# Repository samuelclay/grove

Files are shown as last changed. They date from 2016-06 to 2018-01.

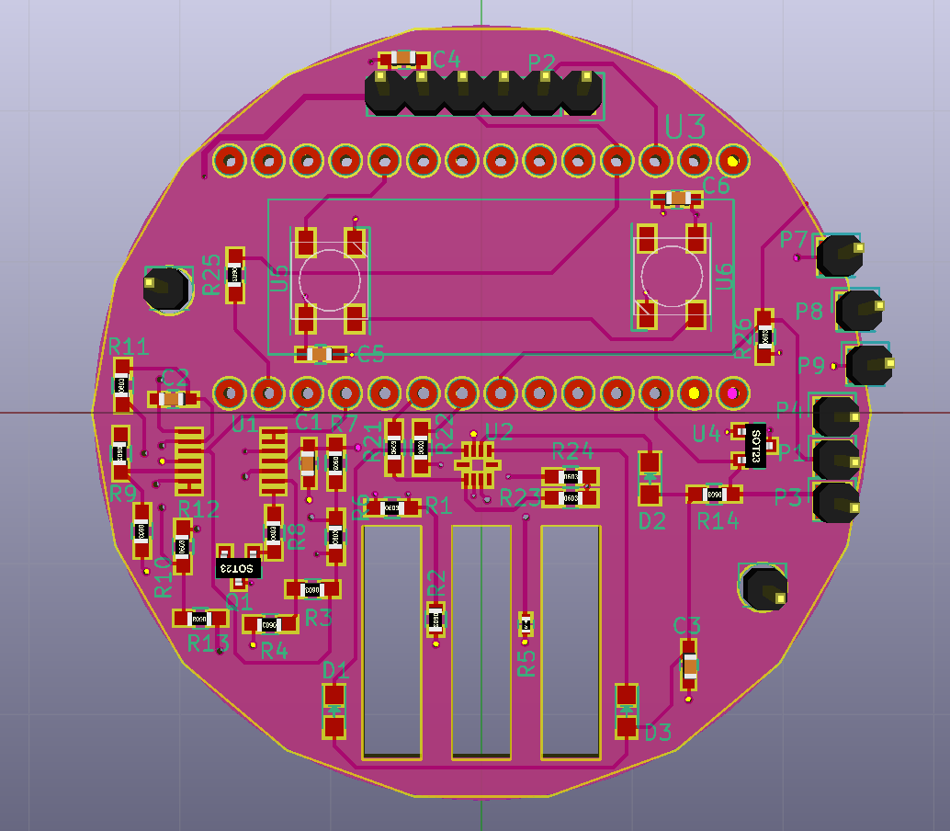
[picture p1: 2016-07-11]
sensor board/3D.PNG

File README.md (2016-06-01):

Grove
=====

Mailing list: grove-electronics@googlegroups.com

# Boards

1) Main board - Teensy shield
    - 4 x 3 pins for 144/m 5m strips on trunk
    - 4 x 5 pins (power + rgb) for dispatcher board
    - 3 pins (power + data) for breathing sensor
    - Power switch
    - PTC fuse + zener diode
    - 4 pins for buck converter, 12V -> 5V
    
2) Sensor board
    - 3 pins from mainboard (power, data)
    - Proximity sensor (SI1143x)
    - IR motion detector
    - "breathing" sensor
    - active LEDs

3) Dispatcher board
    - 4 x 5 pins input (power + rgb)
    - 4 PicoBucks (six pins in, six pins out)
    - 16 x 6 pin RGB LEDs (r±, g±, b±)

# Concerns

1) Power
    - 12V deep cycle marine batteries
    - Charging circuit
    - Solar array
    - Delivering 12V to each tree (voltage drop)
2) Firmware
    - Performance over time
    - Running 4x trunks vs 1 trunk 4 times
3) Lighting
    - Soldering high current LEDs
    - 144/m 5m vs splicing power

# Timeline

- May 31: Initial meeting
- June 8th: Dispatcher board rev #1 sent to printer
- June 9th: Main board rev #1 sent to printer
- June 10th: Sensor board rev #1 sent to printer
- July 1st: Boards return from printer, soldering begins
- July 6th: Final board revisions sent to printer
- July 27th: Final boards return from printer, soldering begins
- August 20th: Installation begins on playa
- August 28th: Burning Man begins

# Useful links:

Grove proposal: https://docs.google.com/presentation/d/1Oe51Et6uq_moFoTw9EoB07Vlh8WwSTc89PW6PQpZ1io/edit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
Grove budget: https://docs.google.com/spreadsheets/d/1ltcCgIae5ANJpvHL2A5ckWDxvADcpXeD_jZIF5hPCvg/edit#gid=0
Prototypes and earlier installation: https://cambridge.nuvustudio.com/studios/grove#tab-proposal-url

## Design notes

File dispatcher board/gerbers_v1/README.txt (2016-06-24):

Specifications
------------------
* 3mils tolerance on drills
* 7mils spacings everywhere (checked)

Files
------------------
grove-dispatcher-Edge.Cuts.gbr Edge Cuts

grove-dispatcher-B.Cu.gbr      copper layer (TOP)
grove-dispatcher-B.Mask.gbr    soldermask layer (TOP)
grove-dispatcher-B.SilkS.gbr   silkscreen layer (TOP)

grove-dispatcher-F.Cu.gbr      copper layer (TOP)
grove-dispatcher-F.Mask.gbr    soldermask layer (TOP)
grove-dispatcher-F.SilkS.gbr   silkscreen layer (TOP)

grove-dispatcher.drl           excellon drill data

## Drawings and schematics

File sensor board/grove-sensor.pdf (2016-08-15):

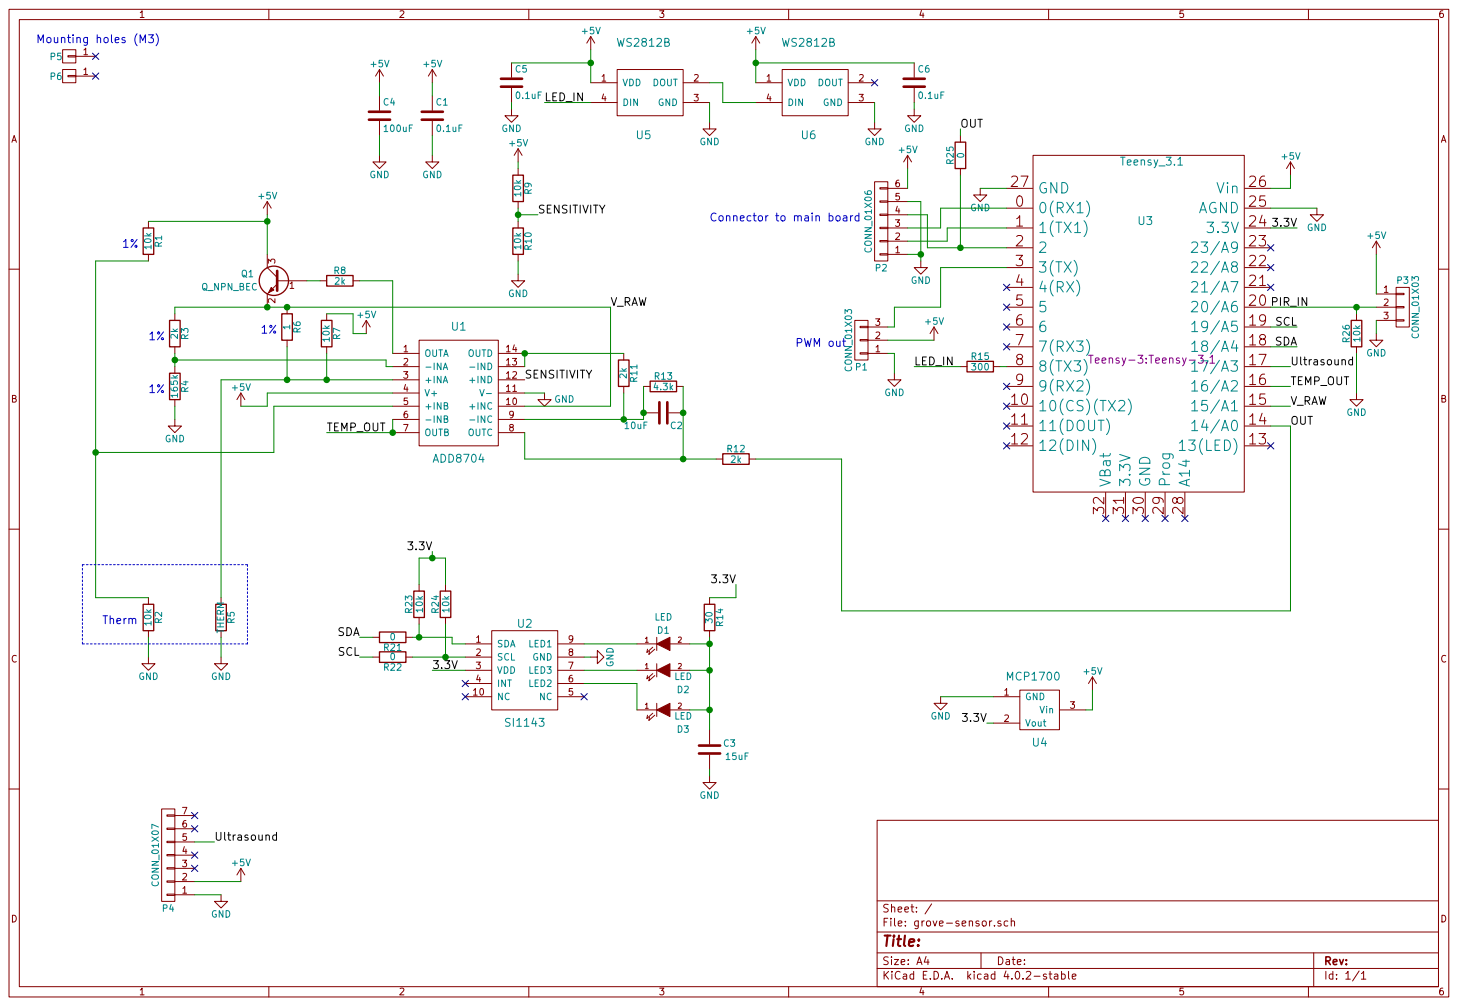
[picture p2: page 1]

+5V Connector to main board

File: grove-sensor.sch Sheet: /
Id: 1/1 Title:

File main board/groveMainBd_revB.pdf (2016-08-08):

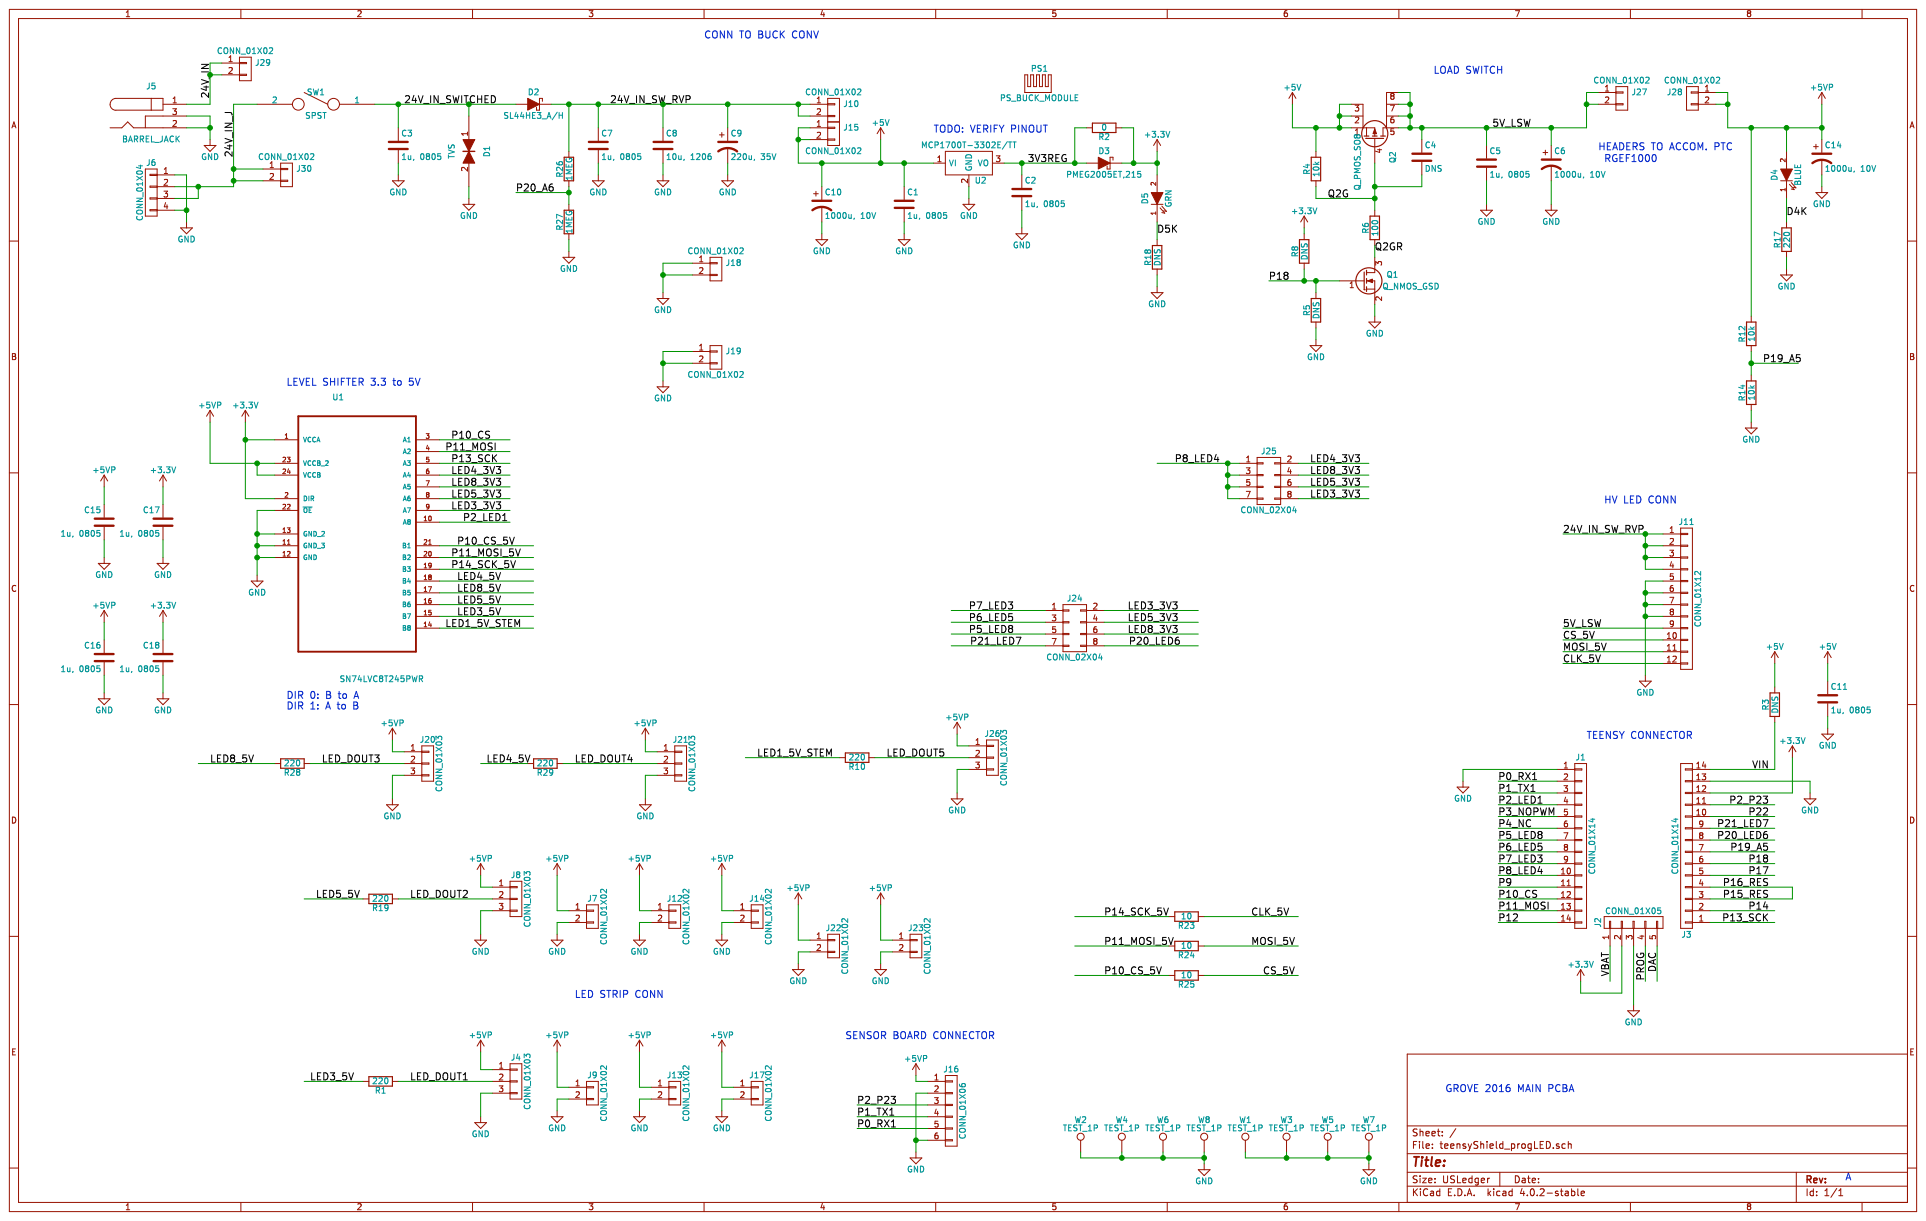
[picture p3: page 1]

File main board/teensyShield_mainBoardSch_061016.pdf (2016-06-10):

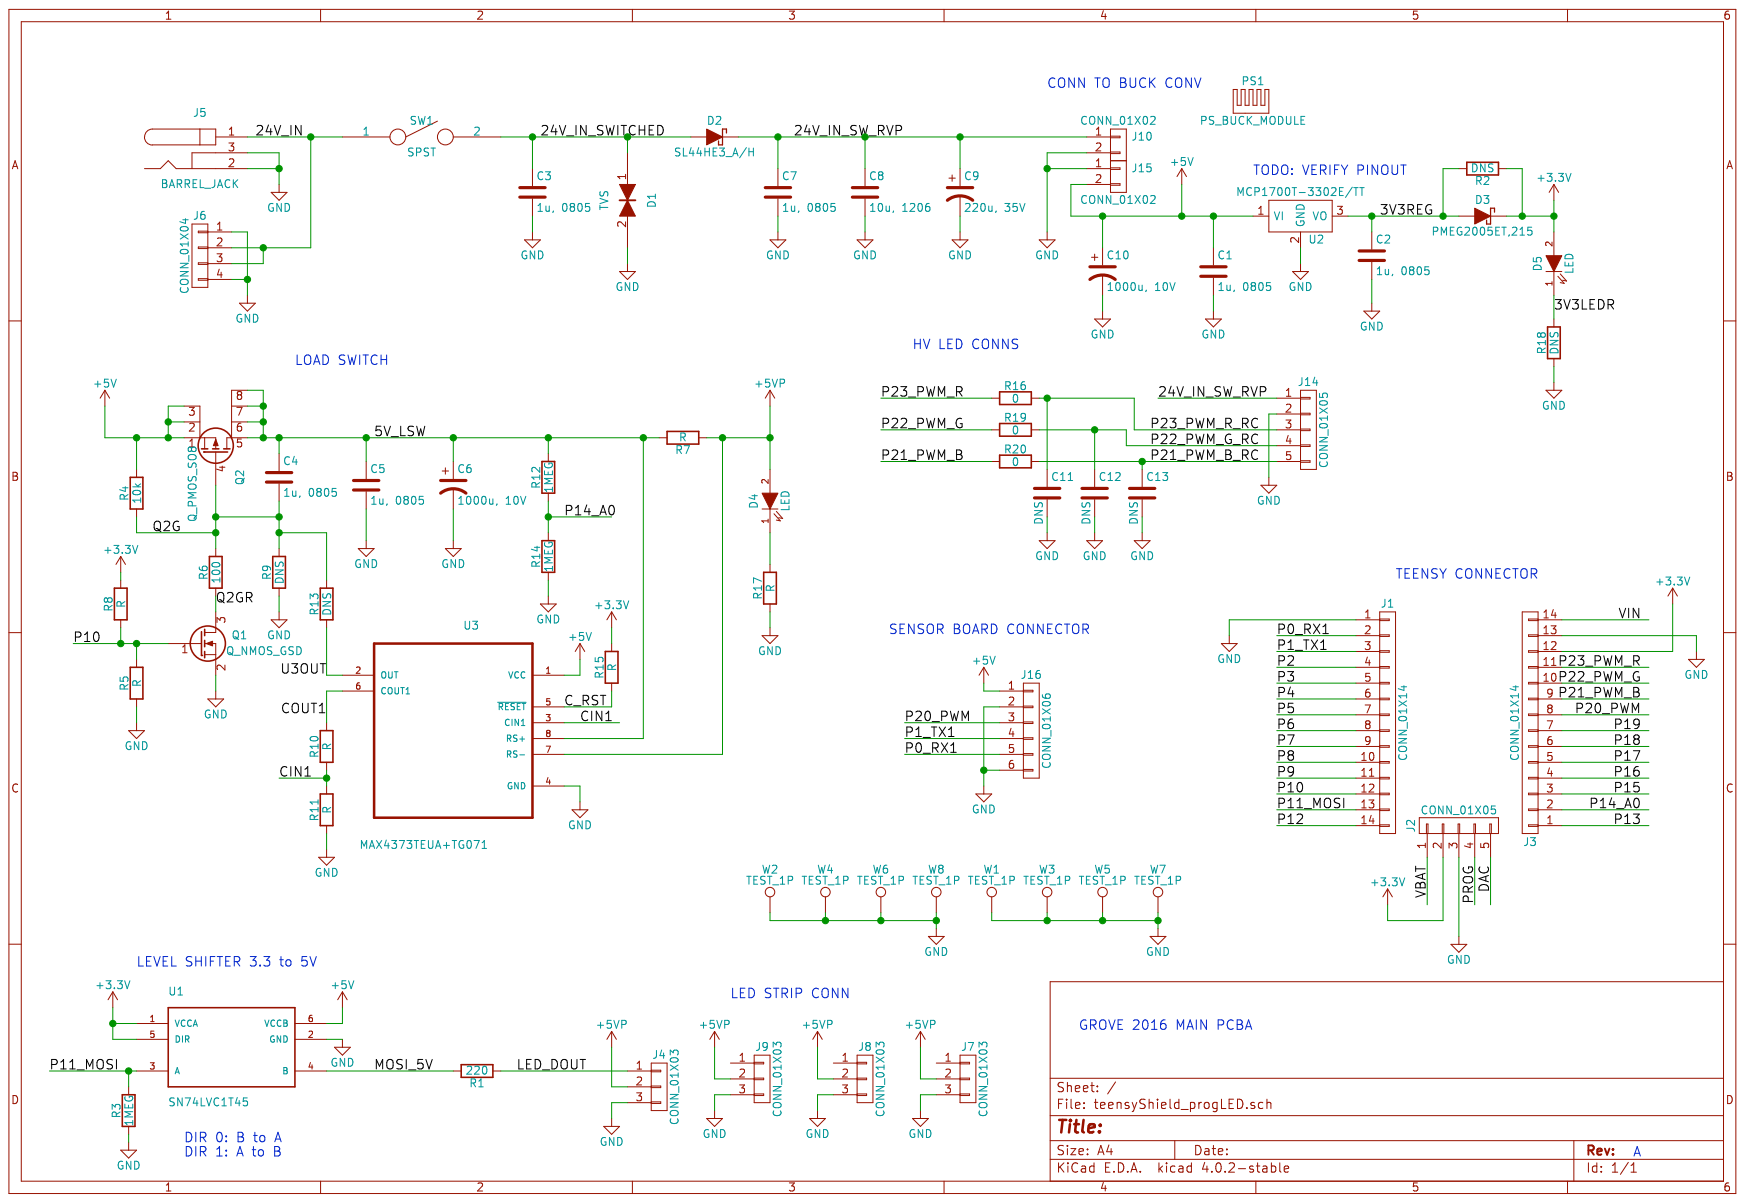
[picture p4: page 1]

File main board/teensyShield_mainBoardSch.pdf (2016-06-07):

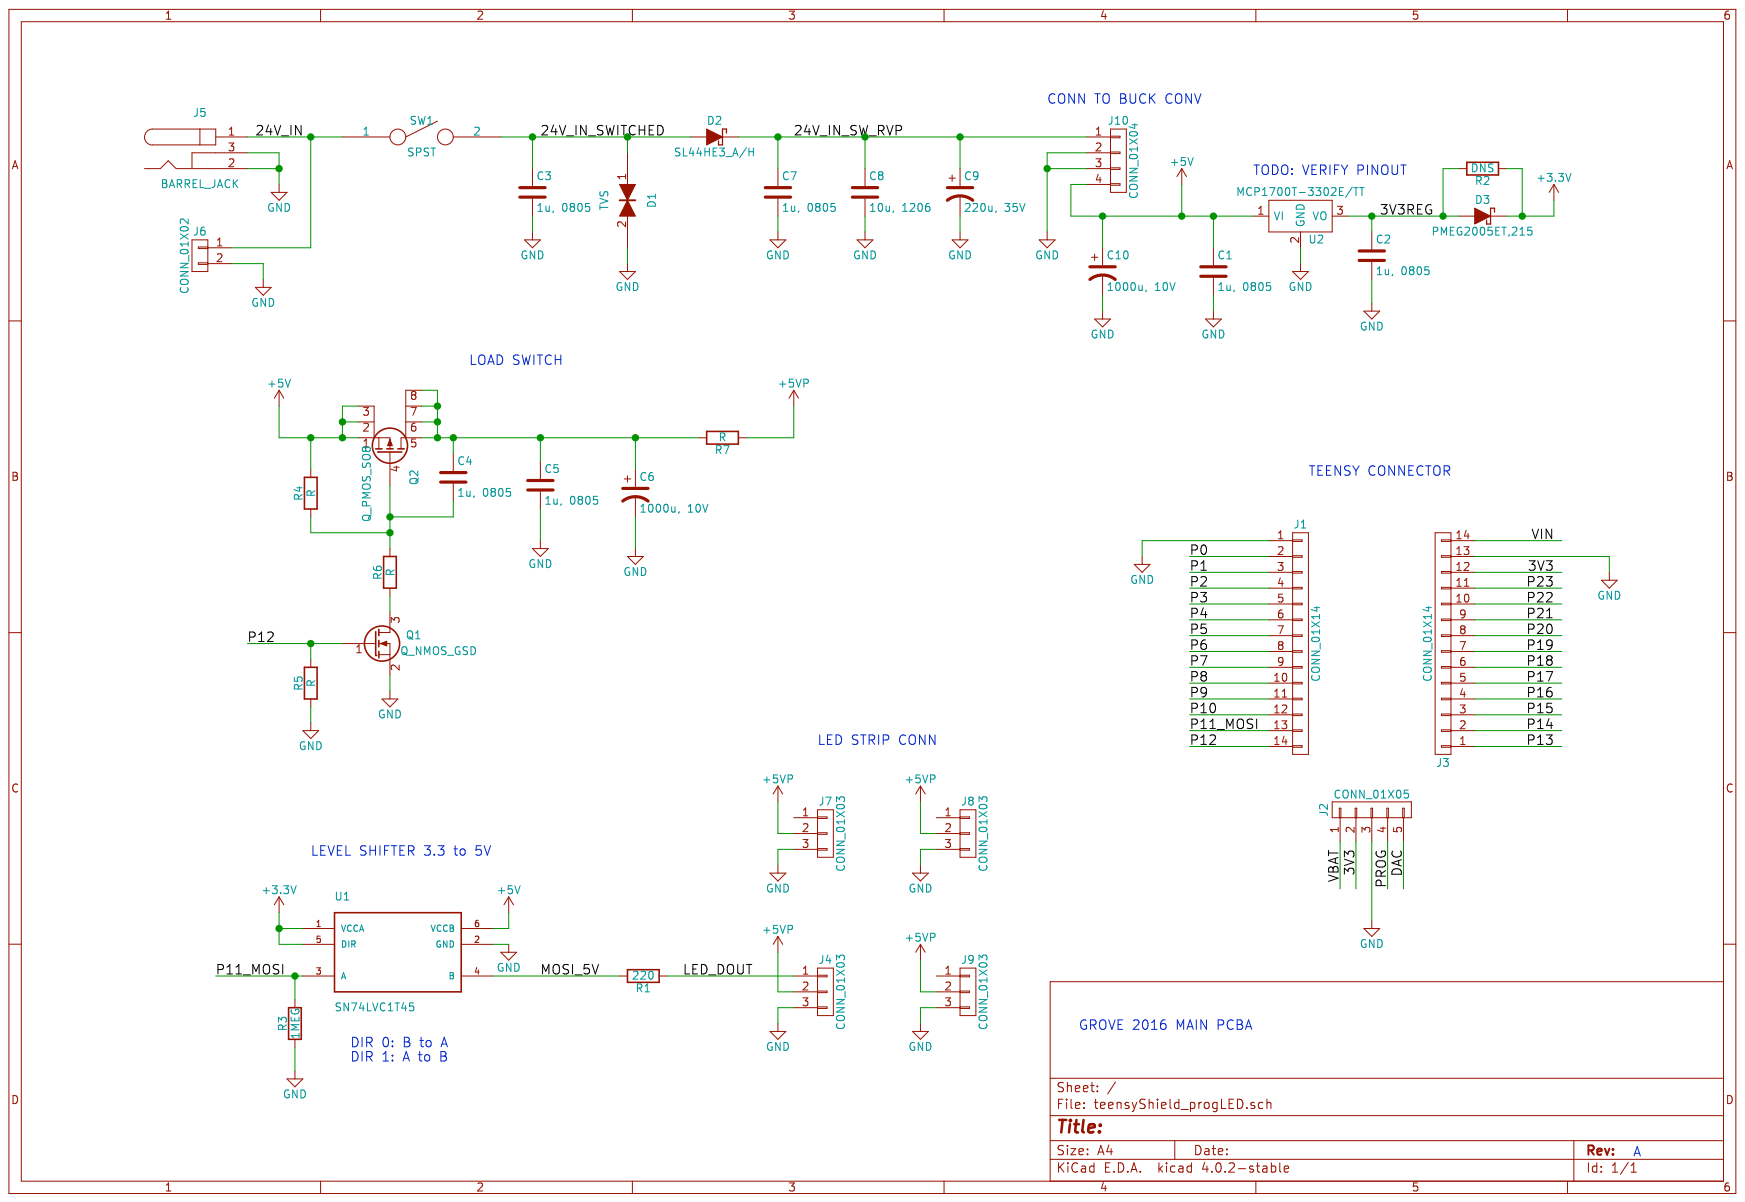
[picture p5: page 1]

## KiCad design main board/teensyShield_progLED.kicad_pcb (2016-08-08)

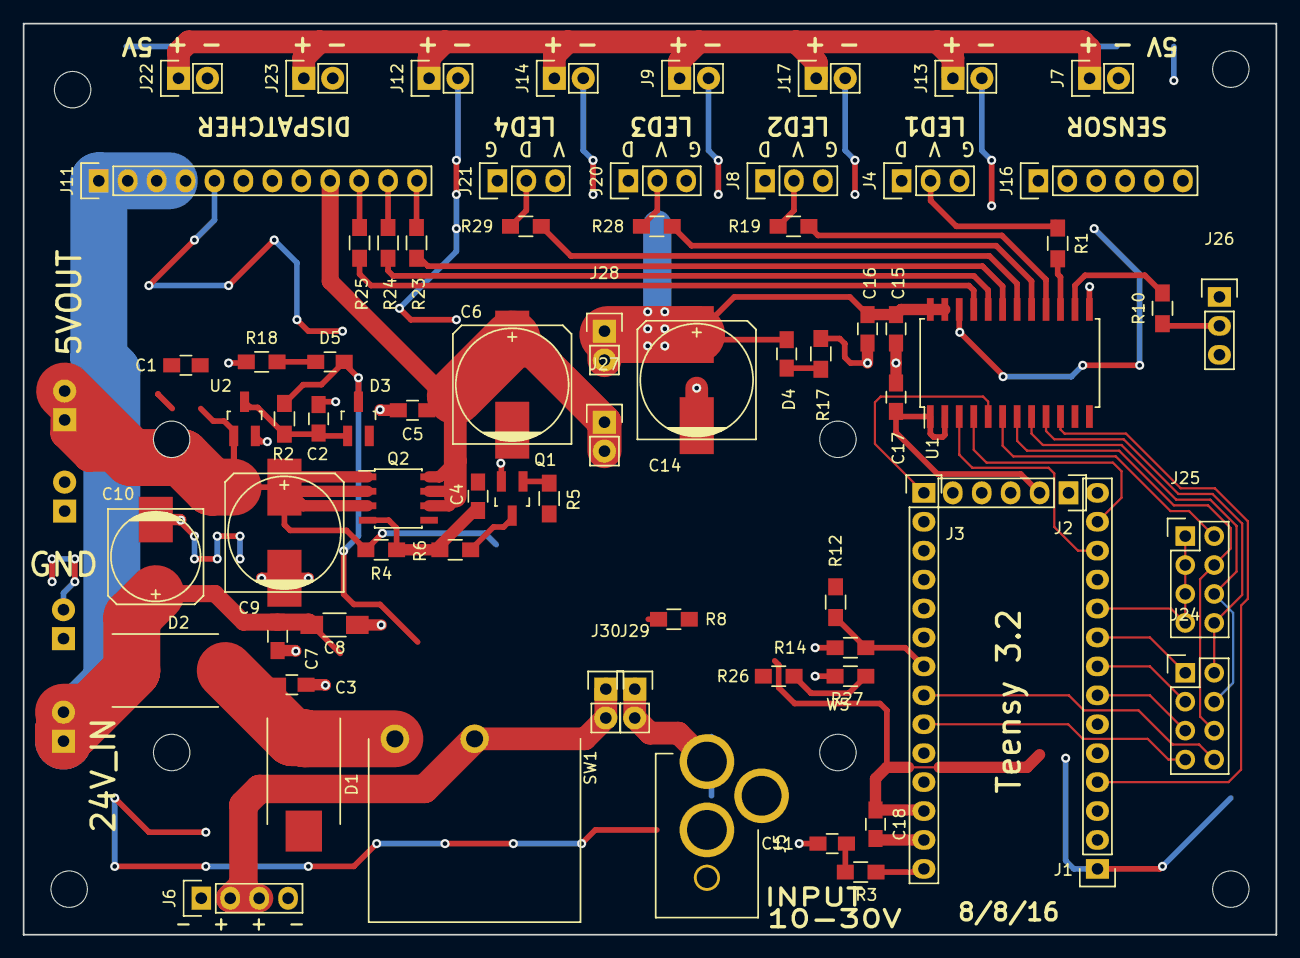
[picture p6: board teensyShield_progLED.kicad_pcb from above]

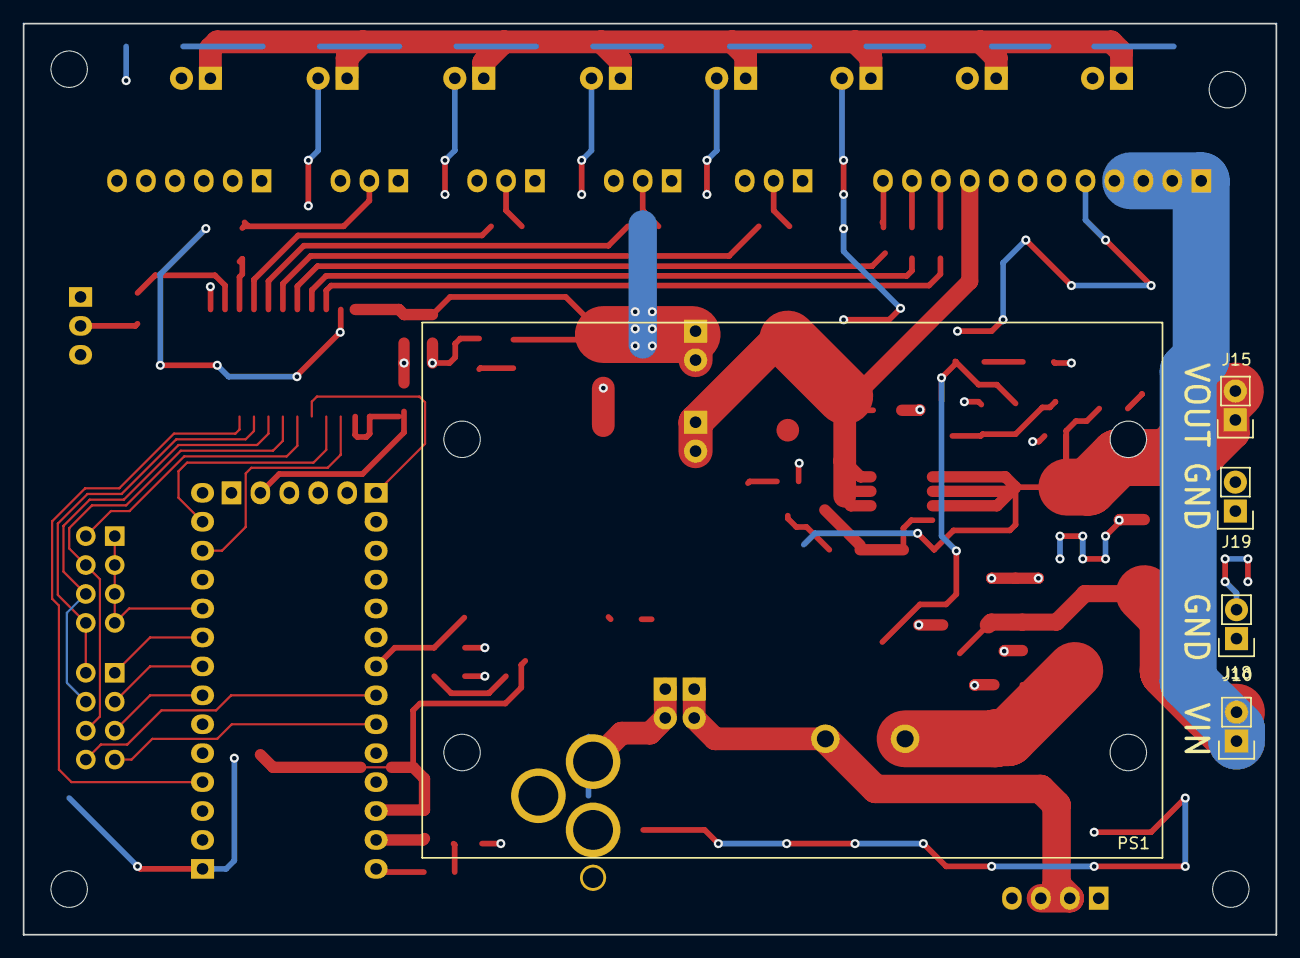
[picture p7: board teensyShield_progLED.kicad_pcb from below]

Board: 2 copper layers, 110.0 x 80.0 mm, 85 parts (5 on the bottom side), 52 nets.

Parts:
C1, C2, C3, C5, C7, C11, C15, C16, C17, C18: 1u, 0805; C_0805_HandSoldering
C4: DNS; C_0805_HandSoldering
C6, C10, C14: 1000u, 10V; c_elec_10x10
C8: 10u, 1206; C_1206_HandSoldering
C9: 220u, 35V; c_elec_8x10
D1: TVS; DO-214AB_Handsoldering
D2: SL44HE3_A/H; DO-214AB_Handsoldering
D3: PMEG2005ET,215; SOT-23_DIODE_Handsoldering
D4: BLUE; C_0805_HandSoldering
D5: GRN; C_0805_HandSoldering
J1, J3: CONN_01X14; Pin_Header_Straight_1x14
J2: CONN_01X05; Pin_Header_Straight_1x05
J4, J8, J20, J21, J26: CONN_01X03; Pin_Header_Straight_1x03
J5: BARREL_JACK; PJ-050AH
J6: CONN_01X04; Pin_Header_Straight_1x04
J7, J9, J10, J12, J13, J14, J15, J17, J18, J19, J22, J23, J27, J28, J29, J30: CONN_01X02; Pin_Header_Straight_1x02
J11: CONN_01X12; Pin_Header_Straight_1x12
J16: CONN_01X06; Pin_Header_Straight_1x06
J24, J25: CONN_02X04; Pin_Header_Straight_2x04
PS1: PS_BUCK_MODULE; TC43200
Q1: Q_NMOS_GSD; SOT-23_Handsoldering
Q2: Q_PMOS_SO8; SOIC-8_3.9x4.9mm_Pitch1.27mm
R1, R10, R17, R19, R28, R29: 220; R_0805_HandSoldering
R2: 0; R_0805_HandSoldering
R3, R5, R8, R18: DNS; R_0805_HandSoldering
R4, R12, R14: 10k; R_0805_HandSoldering
R6: 100; R_0805_HandSoldering
R23, R24, R25: 10; R_0805_HandSoldering
R26, R27: 1MEG; R_0805_HandSoldering
SW1: SPST; R1966ABLKBLKFR
U1: SN74LVC8T245PWR; SOIC-24_7.5x15.4mm_Pitch1.27mm
U2: MCP1700T-3302E/TT; SOT-23_Handsoldering
W1, W2, W3, W4, W5, W6, W7, W8: TEST_1P; MountingHole_3.2mm_M3

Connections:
+3V3: C17.1, C18.1, D3.1, D5.2, J2.2, J3.12, R2.1, R8.2, U1.1, U1.2
+5V: C1.1, C10.1, C11.1, J15.1, J15.2, Q2.1, Q2.2, Q2.3, R3.2, R4.2, U2.1
+5VP: C14.1, C15.1, C16.1, D4.2, J4.1, J7.1, J8.1, J9.1, J12.1, J13.1, J14.1, J16.1, J17.1, J20.1, J21.1, J22.1, J23.1, J26.1, J28.1, J28.2, R12.2, U1.23, U1.24
/3V3REG: C2.1, D3.2, R2.2, U2.3
/5V_LSW: C4.1, C5.1, C6.1, J11.9, J27.1, J27.2, Q2.5, Q2.6, Q2.7, Q2.8
/24V_IN: J5.1, J29.1, J29.2
/24V_IN_J: J6.2, J6.3, J30.1, J30.2, SW1.2
/24V_IN_SWITCHED: C3.1, D1.1, D2.2, SW1.1
/24V_IN_SW_RVP: C7.1, C8.1, C9.1, D2.1, J10.1, J10.2, J11.1, J11.2, J11.3, J11.4, R26.2
/CLK_5V: J11.12, R23.1
/CS_5V: J11.10, R25.1
/D4K: D4.1, R17.2
/D5K: D5.1, R18.2
/LED1_5V_STEM: R10.2, U1.14
/LED3_3V3: J24.2, J25.8, U1.9
/LED3_5V: R1.2, U1.15
/LED4_3V3: J25.2, U1.6
/LED4_5V: R29.2, U1.18
/LED5_3V3: J24.4, J25.6, U1.8
/LED5_5V: R19.2, U1.16
/LED8_3V3: J24.6, J25.4, U1.7
/LED8_5V: R28.2, U1.17
/LED_DOUT1: J4.2, R1.1
/LED_DOUT2: J8.2, R19.1
/LED_DOUT3: J20.2, R28.1
/LED_DOUT4: J21.2, R29.1
/LED_DOUT5: J26.2, R10.1
/MOSI_5V: J11.11, R24.1
/P0_RX1: J1.2, J16.5
/P1_TX1: J1.3, J16.4
/P2_LED1: J1.4, U1.10
/P2_P23: J3.11, J16.3
/P5_LED8: J1.7, J24.5
/P6_LED5: J1.8, J24.3
/P7_LED3: J1.9, J24.1
/P8_LED4: J1.10, J25.1, J25.3, J25.5, J25.7
/P10_CS: J1.12, U1.3
/P10_CS_5V: R25.2, U1.21
/P11_MOSI: J1.13, U1.4
/P11_MOSI_5V: R24.2, U1.20
/P13_SCK: J3.1, U1.5
/P14_SCK_5V: R23.2, U1.19
/P15_RES: J3.3, J3.4
/P18: J3.6, Q1.1, R5.2, R8.1
/P19_A5: J3.7, R12.1, R14.2
/P20_A6: R26.1, R27.2
/P20_LED6: J3.8, J24.8
/P21_LED7: J3.9, J24.7
/Q2G: C4.2, Q2.4, R4.1, R6.2
/Q2GR: Q1.3, R6.1
/VIN: J3.14, R3.1
GND: C1.2, C2.2, C3.2, C5.2, C6.2, C7.2, C8.2, C9.2, C10.2, C11.2, C14.2, C15.2, C16.2, C17.2, C18.2, D1.2, J1.1, J2.3, J3.13, J4.3, J5.2, J5.3, J6.1, J6.4, J7.2, J8.3, J9.2, J11.5, J11.6, J11.7, J11.8, J12.2, J13.2, J14.2, J16.2, J16.6, J17.2, J18.1, J18.2, J19.1, J19.2, J20.3, J21.3, J22.2, J23.2, J26.3, Q1.2, R5.1, R14.1, R17.1, R18.1, R27.1, U1.11, U1.12, U1.13, U1.22, U2.2, W1.1, W2.1, W3.1, W4.1, W5.1, W6.1, W7.1, W8.1

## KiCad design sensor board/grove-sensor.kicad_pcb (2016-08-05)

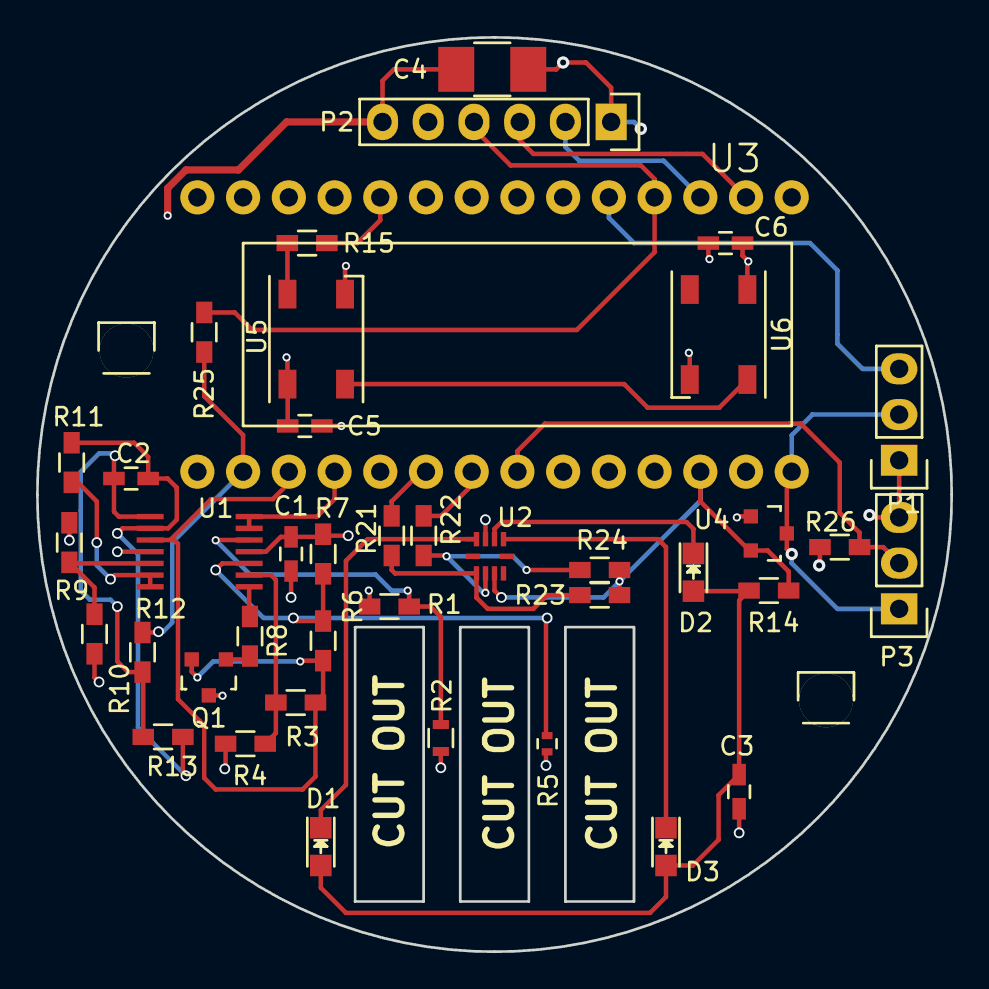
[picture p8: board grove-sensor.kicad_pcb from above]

Board: 4 copper layers, 50.8 x 50.8 mm, 42 parts (0 on the bottom side), 31 nets.

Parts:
C1, C5, C6: 0.1uF; C_0603_HandSoldering
C2: 10uF; C_0603_HandSoldering
C3: 15uF; C_0603_HandSoldering
C4: 100uF; C_1210_HandSoldering
D1, D2, D3: LED; LED_0805
P1, P3: CONN_01X03; Pin_Header_Straight_1x03
P2: CONN_01X06; Pin_Header_Straight_1x06
P5, P6: CONN_01X01; Pin_Header_Straight_1x01
Q1: Q_NPN_BEC; SOT-23
R1, R7, R9, R10, R23, R24, R26: 10k; R_0603_HandSoldering
R2: 10k; R_0603
R3, R8, R11, R12: 2k; R_0603_HandSoldering
R4: 165k; R_0603_HandSoldering
R5: THERM; R_0402
R6: 1; R_0603_HandSoldering
R13: 4.3k; R_0603_HandSoldering
R14: 30; R_0603_HandSoldering
R15: 300; R_0603_HandSoldering
R21, R22, R25: 0; R_0603_HandSoldering
U1: ADD8704; TSSOP-14
U2: SI1143
U3: Teensy_3.1; Teensy-3.1
U4: MCP1700; SOT-23
U5, U6: WS2812B; LED_WS2812B-PLCC4

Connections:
+5V: C1.1, C4.1, C5.1, C6.1, P1.2, P2.6, P3.1, Q1.3, R1.1, R7.1, R9.1, U1.4, U3.26, U4.3, U5.1, U6.1
/3.3V: R14.1, R23.2, R24.2, U2.3, U3.24, U4.2
/LED_IN: R15.1, U5.4
/OUT: R12.2, R25.2, U3.14
/PIR_IN: P3.2, R26.2, U3.20
/SCL: R22.2, U3.19
/SDA: R21.2, U3.18
/SENSITIVITY: R9.2, R10.1, U1.12
/TEMP_OUT: U1.6, U1.7, U3.16
/V_RAW: Q1.2, R3.1, R6.1, U1.10, U3.15
GND: C1.2, C3.1, C4.2, C5.2, C6.2, P1.1, P2.1, P2.5, P3.3, R2.2, R4.2, R5.2, R10.2, R26.1, U1.11, U2.8, U3.25, U3.27, U4.1, U5.3, U6.3
unnamed: C2.1, R12.1, R13.2, U1.8
unnamed: C2.2, R11.2, R13.1, U1.9
unnamed: C3.2, D1.2, D2.2, D3.2, R14.2
unnamed: D1.1, U2.9
unnamed: D2.1, U2.7
unnamed: D3.1, U2.6
unnamed: P1.3, U3.3
unnamed: P2.2, U3.1
unnamed: P2.3, U3.0
unnamed: P2.4, R25.1, U3.2
unnamed: Q1.1, R8.1
unnamed: R1.2, R2.1, U1.5
unnamed: R3.2, R4.1, U1.2
unnamed: R5.1, R6.2, R7.2, U1.3
unnamed: R8.2, U1.1
unnamed: R11.1, U1.13, U1.14
unnamed: R15.2, U3.8
unnamed: R21.1, R23.1, U2.1
unnamed: R22.1, R24.1, U2.2
unnamed: U5.2, U6.4

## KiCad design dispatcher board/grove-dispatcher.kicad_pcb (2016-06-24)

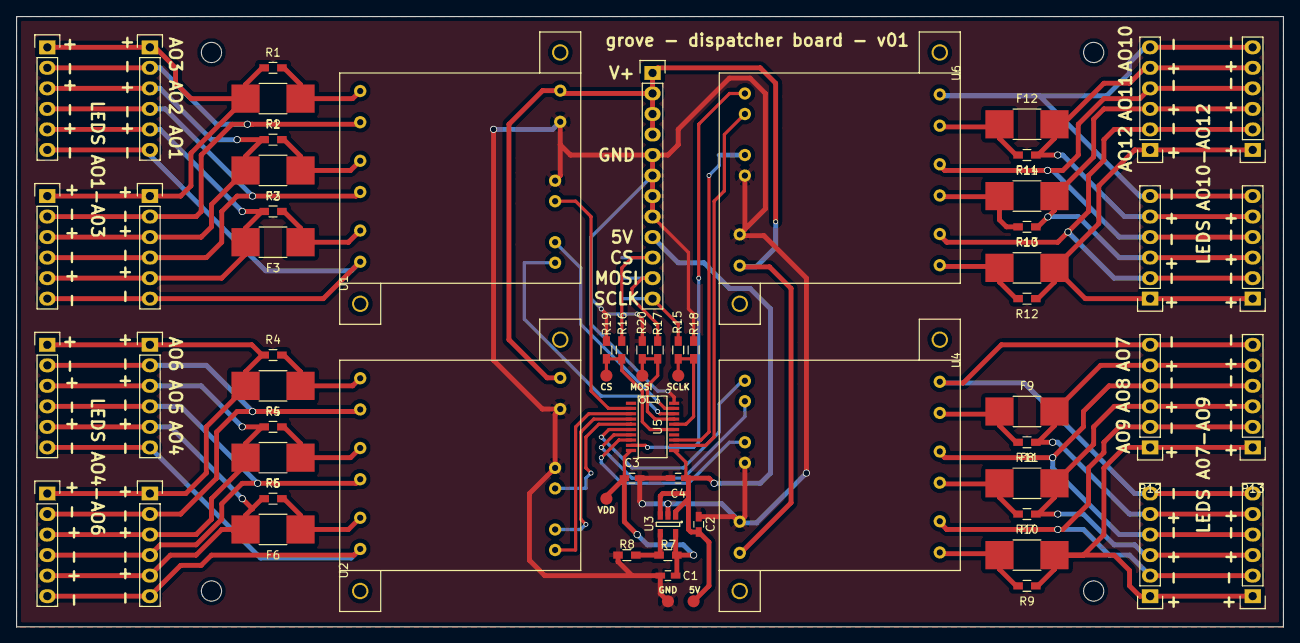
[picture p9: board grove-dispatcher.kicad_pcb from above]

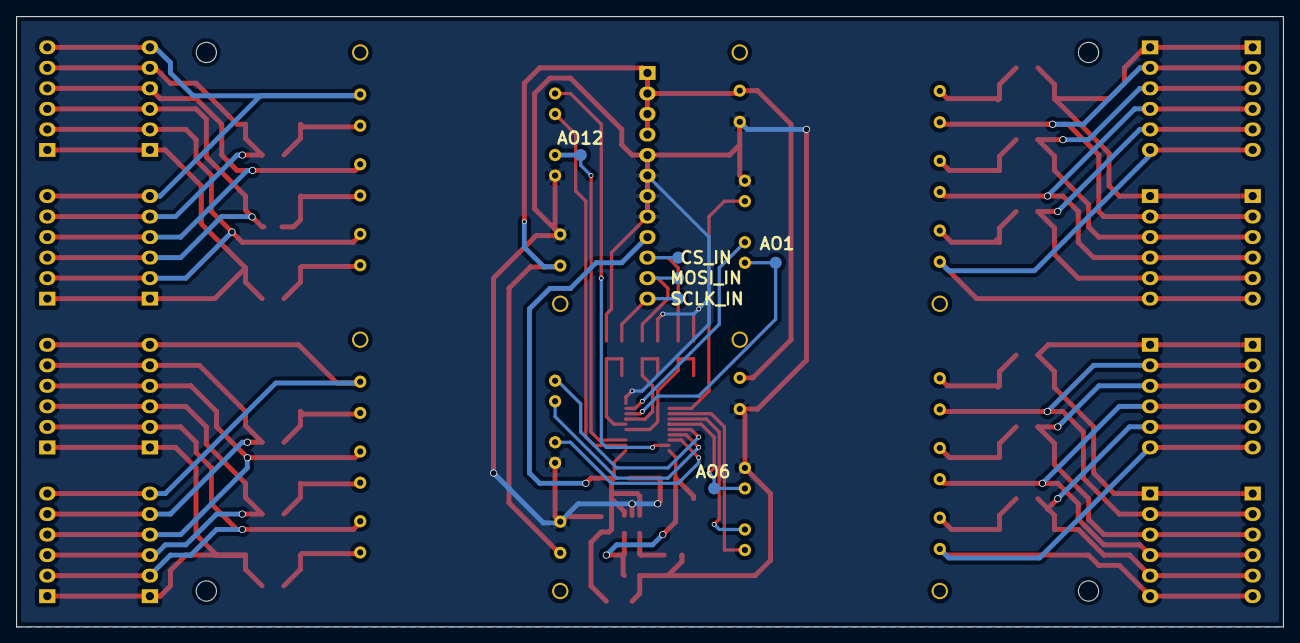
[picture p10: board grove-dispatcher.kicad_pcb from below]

Board: 2 copper layers, 156.8 x 75.6 mm, 71 parts (6 on the bottom side), 59 nets.

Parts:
C1, C2, C3, C4: 1uF; C_0603_HandSoldering
F1, F2, F3, F4, F5, F6, F7, F8, F9, F10, F11, F12: PTC; R_1812_HandSoldering
P1: CONN_01X12; Pin_Header_Straight_1x12
P2, P3, P4, P5, P6, P7, P8, P9, P10, P11, P12, P13, P14, P15, P16, P17: CONN_01X06; Pin_Header_Straight_1x06
R1, R2, R3, R4, R5, R6, R9, R10, R11, R12, R13, R14: 0; R_0603_HandSoldering
R7: ?ohm; R_0603_HandSoldering
R8: ?ohms; R_0603_HandSoldering
R15, R16, R17: 10ohm; R_0603_HandSoldering
R18, R19, R20: 1kOhm; R_0603_HandSoldering
U1, U2, U4, U6: PICO_BUCK
U3: NCP603 ADJ / LD3985G25R; SOT-23-5
U5: BH2221FV; SSOP-20
W1: SCLK; Measurement_Point_Round-SMD-Pad_Small
W2: MOSI; Measurement_Point_Round-SMD-Pad_Small
W3: CS; Measurement_Point_Round-SMD-Pad_Small
W4: 5V; Measurement_Point_Round-SMD-Pad_Small
W5: 2V5; Measurement_Point_Round-SMD-Pad_Small
W6: GND; Measurement_Point_Round-SMD-Pad_Small
W7: AO1; Measurement_Point_Round-SMD-Pad_Small
W8: AO6; Measurement_Point_Round-SMD-Pad_Small
W9: AO12; Measurement_Point_Round-SMD-Pad_Small
W10: SCLK_F; Measurement_Point_Round-SMD-Pad_Small
W11: CS_F; Measurement_Point_Round-SMD-Pad_Small
W12: MOSI_F; Measurement_Point_Round-SMD-Pad_Small

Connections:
+2V5: C1.1, C3.1, R7.1, U3.5, U5.10, W5.1
+5V: C2.1, C4.1, P1.9, U3.1, U3.3, U5.11, W4.1
/AO1: U1.0, U5.18, W7.1
/AO2: U1.1, U5.19
/AO3: U1.2, U5.2
/AO4: U2.0, U5.3
/AO5: U2.1, U5.4
/AO6: U2.2, U5.5, W8.1
/AO7: U4.0, U5.6
/AO8: U4.1, U5.7
/AO9: U4.2, U5.8
/AO10: U5.9, U6.0
/AO11: U5.12, U6.1
/AO12: U5.13, U6.2, W9.1
/CS_5V: P1.10, R16.2, W3.1
/CS_IN: R16.1, R19.1, U5.15, W11.1
/MOSI_5V: P1.11, R17.2, W2.1
/MOSI_IN: R17.1, R20.1, U5.17, W12.1
/SCLK_5V: P1.12, R15.2, W1.1
/SCLK_IN: R15.1, R18.1, U5.16, W10.1
/V+: P1.1, P1.2, P1.3, P1.4, U1.5, U2.5, U4.5, U6.5
GND: C1.2, C2.2, C3.2, C4.2, P1.5, P1.6, P1.7, P1.8, R8.2, R18.2, R19.2, R20.2, U1.3, U1.4, U2.3, U2.4, U3.2, U4.3, U4.4, U5.20, U6.3, U6.4, W6.1
unnamed: F1.1, R1.2, U1.6
unnamed: F1.2, P2.1, P3.1, P4.1, P5.1, R1.1
unnamed: F2.1, R2.2, U1.8
unnamed: F2.2, P2.3, P3.3, P4.3, P5.3, R2.1
unnamed: F3.1, R3.2, U1.10
unnamed: F3.2, P2.5, P3.5, P4.5, P5.5, R3.1
unnamed: F4.1, R4.2, U2.6
unnamed: F4.2, P6.1, P7.1, P8.1, P9.1, R4.1
unnamed: F5.1, R5.2, U2.8
unnamed: F5.2, P6.3, P7.3, P8.3, P9.3, R5.1
unnamed: F6.1, R6.2, U2.10
unnamed: F6.2, P6.5, P7.5, P8.5, P9.5, R6.1
unnamed: F7.1, R9.2, U4.6
unnamed: F7.2, P10.1, P11.1, P12.1, P13.1, R9.1
unnamed: F8.1, R10.2, U4.8
unnamed: F8.2, P10.3, P11.3, P12.3, P13.3, R10.1
unnamed: F9.1, R11.2, U4.10
unnamed: F9.2, P10.5, P11.5, P12.5, P13.5, R11.1
unnamed: F10.1, R12.2, U6.6
unnamed: F10.2, P14.1, P15.1, P16.1, P17.1, R12.1
unnamed: F11.1, R13.2, U6.8
unnamed: F11.2, P14.3, P15.3, P16.3, P17.3, R13.1
unnamed: F12.1, R14.2, U6.10
unnamed: F12.2, P14.5, P15.5, P16.5, P17.5, R14.1
unnamed: P2.2, P3.2, P4.2, P5.2, U1.7
unnamed: P2.4, P3.4, P4.4, P5.4, U1.9
unnamed: P2.6, P3.6, P4.6, P5.6, U1.11
unnamed: P6.2, P7.2, P8.2, P9.2, U2.7
unnamed: P6.4, P7.4, P8.4, P9.4, U2.9
unnamed: P6.6, P7.6, P8.6, P9.6, U2.11
unnamed: P10.2, P11.2, P12.2, P13.2, U4.7
unnamed: P10.4, P11.4, P12.4, P13.4, U4.9
unnamed: P10.6, P11.6, P12.6, P13.6, U4.11
unnamed: P14.2, P15.2, P16.2, P17.2, U6.7
unnamed: P14.4, P15.4, P16.4, P17.4, U6.9
unnamed: P14.6, P15.6, P16.6, P17.6, U6.11
unnamed: R7.2, R8.1, U3.4

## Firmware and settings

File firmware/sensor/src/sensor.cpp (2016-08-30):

#include "sensor.h"

void setup() { 
    Serial.begin(9600);
    // HWSERIAL.begin(9600);

    leds.begin();
    leds.show();

    pinMode(PIR_PIN, INPUT_PULLUP);
    pinMode(SERVO_PIN, OUTPUT);

    pinMode(PIR_REMOTE_PIN, INPUT);
    pinMode(BREATH_REMOTE_PIN, OUTPUT);

    servo.attach(SERVO_PIN); //set up the servo on pin 3
    servo.write(servoOpenPos); //open flower to start
    servo.detach();

    for (int i = 0; i < WIND_HIST_LEN; i++) {
        windHistory[i] = 0;
    }

#ifdef USE_IR_PROX
    if (!pulse.isPresent()) {
      Serial.print("No SI114x found on port ");
      Serial.println(SI114_PORT);
    } else {
        Serial.println("setup");
    }
    pulse.initPulsePlug(); //Initialize I2C bus
    pulse.setLEDcurrents(6, 6, 6); //set prox sensor LED currents
    pulse.setLEDdrive(4, 2, 1); //set which LEDs are active on which pulse
#endif

    closeFlower();
}

void setOnboardLEDs(uint8_t rValue, uint8_t gValue, uint8_t bValue) {
    for (int i = 0; i < 60; i++) {
        leds.setPixelColor(0, rValue, gValue, bValue);
        leds.setPixelColor(1, rValue, gValue, bValue);
    }
    leds.show();
}

int getRawWind() {
    return analogRead(RAW_VOLT_ANALOG_WIND_SENSOR_PIN);
}

int getRawWindTemp() {
    return analogRead(TEMPERATURE_ANALOG_WIND_SENSOR_PIN);
}

void openFlower() {
    servoTargetPosition = servoOpenPos;
    servoStartPosition = servoPosition;
    flowerOpenStartTime = millis();

    ledStartColorR = ledCloseColorR;
    ledStartColorG = ledCloseColorG;
    ledStartColorB = ledCloseColorB;

    ledEndColorR = ledOpenColorR;
    ledEndColorG = ledOpenColorG;
    ledEndColorB = ledOpenColorB;

    fadeStartTime = millis();
}

void closeFlower() {
    servoTargetPosition = servoClosePos;
    servoStartPosition = servoPosition;
    flowerOpenStartTime = millis();

    ledStartColorR = ledOpenColorR;
    ledStartColorG = ledOpenColorG;
    ledStartColorB = ledOpenColorB;

    ledEndColorR = ledCloseColorR;
    ledEndColorG = ledCloseColorG;
    ledEndColorB = ledCloseColorB;

    fadeStartTime = millis();
}

void updateLEDs() {
    long now = millis();
    if (now - lastLedUpdateTime > ledUpdateInterval) {
        lastLedUpdateTime = now;
        long deltaT = now - fadeStartTime;
        if (deltaT <= fadeTime) {
            setOnboardLEDs(
                (ledEndColorR - ledStartColorR) * deltaT / fadeTime + ledStartColorR,
                (ledEndColorG - ledStartColorG) * deltaT / fadeTime + ledStartColorG,
                (ledEndColorB - ledStartColorB) * deltaT / fadeTime + ledStartColorB
            );   
        } else {
            if (overallState == STATE_NEUTRAL) {
                setOnboardLEDs(
                    ledCloseColorR,
                    ledCloseColorG,
                    ledCloseColorB
                );
            } else if (overallState == STATE_OPEN) {
                setOnboardLEDs(
                    ledOpenColorR,
                    ledOpenColorG,
                    ledOpenColorB
                );
            } else if (overallState == STATE_PROX) {
                setOnboardLEDs(
                    ledProxColorR,
                    ledProxColorG,
                    ledProxColorB
                );
            }
        }
    }
}

void updateFlowerServo() {
    long deltaT = millis() - flowerOpenStartTime;
    if (deltaT <= flowerOpenTime) {
        if (!isOpenOrClosing) {
            servo.attach(SERVO_PIN); //set up the servo on pin 3
            isOpenOrClosing = true;
        }
        servoPosition = (servoTargetPosition - servoStartPosition) * deltaT / flowerOpenTime + servoStartPosition;
        servo.write(servoPosition); //Close flower to start
    } else {
        if (isOpenOrClosing) {
            servo.detach();
            isOpenOrClosing = false;
        }   
    }
}

const int samples = 4;            // samples for smoothing 1 to 10 seem useful
                                  // increase for smoother waveform (with less resolution) 
float Avect = 0.0; 
float Bvect = 0.0;
float Cvect = 0.0;
float Tvect, x, y, angle = 0;


// some printing options for experimentation (sketch is about the same)
//#define SEND_TO_PROCESSING_SKETCH
#define PRINT_RAW_LED_VALUES   // prints Raw LED values for debug or experimenting
// #define PRINT_AMBIENT_LIGHT_SAMPLING   // also samples ambient slight (slightly slower)
                                          // good for ambient light experiments, comparing output with ambient
 
unsigned long lastMillis, red, IR1, IR2;


void printProx() {         
}

float getWind() {
    // This code is from Modern Devices

    //Wind sensor globals
    const float zeroWindAdjustment =  .2; // negative numbers yield smaller wind speeds and vice versa.
    int TMP_Therm_ADunits;  //temp termistor value from wind sensor
    float RV_Wind_ADunits;    //RV output from wind sensor
    float RV_Wind_Volts;
    // int TempCtimes100;
    float zeroWind_ADunits;
    float zeroWind_volts;
    float WindSpeed_MPH;

    TMP_Therm_ADunits = analogRead(TEMPERATURE_ANALOG_WIND_SENSOR_PIN);
    RV_Wind_ADunits = analogRead(RAW_VOLT_ANALOG_WIND_SENSOR_PIN);
    RV_Wind_Volts = (RV_Wind_ADunits *  0.0048828125);

    // these are all derived from regressions from raw data as such they depend on a lot of experimental factors
    // such as accuracy of temp sensors, and voltage at the actual wind sensor, (wire losses) which were unaccouted for.
    // TempCtimes100 = (0.005 * ((float)TMP_Therm_ADunits * (float)TMP_Therm_ADunits)) - (16.862 * (float)TMP_Therm_ADunits) + 9075.4;

    zeroWind_ADunits = -0.0006 * ((float)TMP_Therm_ADunits * (float)TMP_Therm_ADunits) + 1.0727 * (float)TMP_Therm_ADunits + 47.172; //  13.0C  553  482.39

    zeroWind_volts = (zeroWind_ADunits * 0.0048828125) - zeroWindAdjustment;

    // This from a regression from data in the form of
    // Vraw = V0 + b * WindSpeed ^ c
    // V0 is zero wind at a particular temperature
    // The constants b and c were determined by some Excel wrangling with the solver.

    WindSpeed_MPH =  pow(((RV_Wind_Volts - zeroWind_volts) / .2300) , 2.7265);

    return WindSpeed_MPH;
}

int getUltrasonic(){
    return analogRead(ULTRASONIC_ANALOG_PIN);
}

void runWindAvgs() {
    long now = millis();
    if (now - lastWindSampleTime > windSampleInterval) {
        // Currently tuned to sample every 20ms roughly
        int raw = getRawWind();

        lowWindAvg = lowWindAvg * lowWindAvgFactor + raw * (1 - lowWindAvgFactor);
        highWindAvg = highWindAvg * highWindAvgFactor + raw * (1 - highWindAvgFactor);

        lastBpassWind = bpassWind;
        bpassWind = (int)(highWindAvg-lowWindAvg);
        windHistory[windHistoryIndex] = bpassWind - lastBpassWind;
        // Serial.print(" ---> Wind history #");
        // Serial.print(windHistoryIndex);
        // Serial.print(": ");
        // Serial.println(windHistory[windHistoryIndex]);
        windHistoryIndex++;

        if (windHistoryIndex >= WIND_HIST_LEN) windHistoryIndex = 0;

        lastWindSampleTime = now;
    }
}

int maxBpassHistory() {
    int maxVal = -1000000;
    for (int i = 0; i < WIND_HIST_LEN; i++) {
        if (windHistory[i] > maxVal) maxVal = windHistory[i];
    }
    return maxVal;
}

void runBreathDetection() {
    int diffSum = 0;
    for (int i = 0; i < WIND_HIST_LEN; i++) {
        diffSum += windHistory[i];
    }
    // Serial.print(" ---> runBreathDetection: ");
    // Serial.print(breathState);
    // Serial.print(" -> ");
    // Serial.println(diffSum);
    if (diffSum < -10 && breathState == REST) {
        breathOn();
    } else if (diffSum > -2 && breathState == BREATH) {
        breathOff();
    }
}

void breathOn() {
    breathState = BREATH;
    digitalWrite(BREATH_REMOTE_PIN, HIGH);
    // HWSERIAL.print("B");
    // Serial.println("B");
}

void breathOff() {
    breathState = REST;
    digitalWrite(BREATH_REMOTE_PIN, LOW);
    // HWSERIAL.print("E");
    // Serial.println("E");
}

void updatePIR() {
    long now = millis();
    if (now < 5000) return; // Let the PIR setup
    if (now - lastPIRSampleTime > pirSampleInterval) {
        int value = digitalRead(PIR_PIN);

        pirHistory[pirHistoryIndex] = value;
        pirHistoryIndex++;
        if (pirHistoryIndex >= PIR_HIST_LEN) pirHistoryIndex = 0;

        PirState newState = PIR_ON;

        for (int i = 0; i < PIR_HIST_LEN; i++) {
            if (pirHistory[i] == 1) {
                newState = PIR_OFF;
                break;
            }
        }

        pirState = newState;

        if (pirState == PIR_ON) {
            openTimeoutLastEvent = now;
        }

        lastPIRSampleTime = now;
    }
}

void updateProx() {
    long now = millis();
    if (now - lastUltraSampleTime > ultraSampleInterval) {
        int ultraVal = (int)ultrasonic.Ranging(CM);
        
        Serial.print(" ---> Ultrasonic: ");
        Serial.println(ultraVal);
        ultraHistory[ultraHistoryIndex] = ultraVal;
        ultraHistoryIndex++;
        if (ultraHistoryIndex >= ULTRA_HIST_LEN) ultraHistoryIndex = 0;

        lastUltraSampleTime = now;

        isProximate = false;
        for (int i = 0; i < ULTRA_HIST_LEN; i++) {
            if (ultraHistory[i] < ultraThres) {
                isProximate = true;
                break;
            }
        }

    }
}

bool isProx() {
#ifdef FAKE_PROX
    return true;
#else
    return isProximate;
#endif
}

void evaluateState() {
    switch (overallState) {
        case STATE_NEUTRAL: {
            // if (pirState == PIR_ON) {
            if (remoteState == STATE_OPEN) {
                overallState = STATE_OPEN;
                // HWSERIAL.print("O");
                // Serial.println("O");
                openFlower();
            }
            break;
        }
        case STATE_OPEN: {
            // long now = millis();
            // if (now - openTimeoutLastEvent > openTimeout) {
            if (remoteState == STATE_NEUTRAL) {
                // HWSERIAL.print("C");
                // Serial.println("C");
                overallState = STATE_NEUTRAL;
                closeFlower();
            } else if (isProx()) {
                overallState = STATE_PROX;
                // HWSERIAL.print("P");
                // Serial.println("P");
            }
            break;
        }
        case STATE_PROX : {
            if (remoteState == STATE_NEUTRAL) {
                // HWSERIAL.print("C");
                // Serial.println("C");
                overallState = STATE_NEUTRAL;
                closeFlower();
            } else if (!isProx()) {
                overallState = STATE_OPEN;
                breathOff();
                // HWSERIAL.print("F");
                // Serial.println("F");
            } else {
                runBreathDetection();
            }
            break;
        }
    }

}

void readRemoteState() {
    long now = millis();
    if (now - lastRemotePIRRead > remotePIRReadInteval) {
        int value = digitalRead(PIR_REMOTE_PIN);
        
        if (value == HIGH) {
            remoteState = STATE_OPEN;
        } else {
            remoteState = STATE_NEUTRAL;
        }

        lastRemotePIRRead = now;
    }

    // if (HWSERIAL.available() > 0) {
    //     uint8_t incomingByte;
    //     incomingByte = HWSERIAL.read();
    //     // Serial.println(incomingByte, HEX);
        
    //     if (incomingByte == 'O') {
    //         remoteState = STATE_OPEN;
    //     } else if (incomingByte == 'C') {
    //         remoteState = STATE_NEUTRAL;
    //     }
    // }
}

void loop() {
    readRemoteState();
    updateLEDs();
    updateFlowerServo();
    // updatePIR();
    
    runWindAvgs();
    updateProx();

    evaluateState();
    // runBreathDetection();

    // if (millis() % 2000 < 1000) {
    //     runBreathDetection();
    // } else {
    //     Serial.print(runningAvg);
    //     Serial.print("\t");
    //     Serial.println(pirState);
    // }

}

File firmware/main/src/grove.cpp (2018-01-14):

#include "grove.h"
#include "WS2812.h"

void setup() { 
    leds.begin();
    leds.show();
    randomSeed(analogRead(0));
    
    breathState = STATE_RESTING;
    proximityState = STATE_PIR_INACTIVE;
    pinMode (slaveSelectPin, OUTPUT);
    pinMode(PIR1_PIN, INPUT_PULLUP);

    pinMode(PIR_REMOTE_PIN, OUTPUT);
    pinMode(BREATH_REMOTE_PIN, INPUT);

    SPI.begin(); 

    Serial.begin(9600); // USB is always 12 Mbit/sec
    // HWSERIAL.begin(9600);
    
    clearDispatcher();

    return;

    testDispatcherRGB(1);
}

void clearDispatcher() {
    setDispatcherGlobalRGB(0, 0, 0);
}

void setDispatcherGlobalRGB(uint8_t rValue, uint8_t gValue, uint8_t bValue) {
    for (uint8_t c = 0; c <= 4; c++) {
        dispatcher(c*3 + 1, rValue);
        dispatcher(c*3 + 2, gValue);
        dispatcher(c*3 + 3, bValue);
    }
}

void testDispatcherRGB(int delayTime) {
    for (uint8_t cGroup = 0; cGroup < 3; cGroup++) {
        // Raise light
        for (uint8_t i=0; i < 255; i++) {
            setDispatcherGlobalRGB(
                cGroup == 0 ? i : 0,
                cGroup == 1 ? i : 0,
                cGroup == 2 ? i : 0
            );
            delay(delayTime);
        }
        // Lower light
        for (uint8_t i=255; i > 0; i--) {
            setDispatcherGlobalRGB(
                cGroup == 0 ? i : 0,
                cGroup == 1 ? i : 0,
                cGroup == 2 ? i : 0
            );
            delay(delayTime);
        }
    }
}

void loop() {
    addRandomDrip();
    advanceRestDrips();
    
    updatePIR(0);
    updatePIR(1);
    transmitSensor();
    // receiveSensor();
    
#ifdef RANDOMBREATHS
    if (millis() % (60 * 1000) < 5000) {
        addBreath();
    }
#else
    if (proximityState == STATE_PIR_ACTIVE && detectedBreath) {
        addBreath();
    }
#endif
    advanceBreaths();
    
    runLeaves();
    runBase();
    
    leds.show();    
}

/**
 * Set the analog output on the dispatcher board.
 * Channels are numbered 1 to 12 inclusive (THEY DON'T START AT ZERO !!) 
 * value is 0-255 range analog output of the dac/LED brightness
 */
void dispatcher(uint8_t chan, uint8_t value) {
    // We could normalize here to a "real" range
    // There's nothing below 45 because below 0.5 the pico buck is off
    // value = value * 210 / 255;
    // if (value > 0) value += 45;

    // take the SS pin low to select the chip:
    SPI.beginTransaction(dispatcherSPISettings);

    digitalWrite(slaveSelectPin, LOW);
    //  send in the address and value via SPI:
    SPI.transfer(flipByte((chan & 0x0F) << 4));
    SPI.transfer(value);
    // take the SS pin high to de-select the chip:
    digitalWrite(slaveSelectPin,HIGH);

    SPI.endTransaction();
}

uint8_t flipByte(uint8_t val) {
    uint8_t result = 0;
    for (uint8_t i = 0; i < 8; i++) {
        result |= ((val & ((0x01) << i)) >> i) << (7-i);
    }
    return result;
}

void addRandomDrip() {
    // Wait until drip is far enough away from beginning
    float distanceTraveled = 0;
    int previousLength = 0;
    int d = dripCount % DRIP_LIMIT;
    
    if (dripCount) {
        int latestDripIndex = d - 1;
        if (latestDripIndex < 0) latestDripIndex = DRIP_LIMIT - 1; // wrap around
        int latestDripStart = dripStarts[latestDripIndex];
        // distanceTraveled = (millis() - latestDripStart) / float(REST_DRIP_TRIP_MS);
        distanceTraveled = dripEase[latestDripIndex].easeIn(float(millis() - latestDripStart));
        previousLength = dripWidth[latestDripIndex];
        
        // Don't start a new drip if the latest drip isn't done coming out
        if (distanceTraveled <= previousLength/2+1) {
            // Serial.print(" ---> Not starting drip, last not done yet: ");
            // Serial.print(distanceTraveled);
            // Serial.print(" <= ");
            // Serial.println(previousLength/2+1);
            return;
        } else if (newDripDelayEnd == 0) {
            newDripDelayEnd = millis() + random(REST_DRIP_DELAY_MIN, REST_DRIP_DELAY_MAX);
        }
    }

    // Serial.print(" ---> New Drip? (#");
    // Serial.print(dripCount);
    // Serial.print("): ");
    // Serial.print(distanceTraveled);
    // Serial.print(" -- ");
    // Serial.print(furthestBreathPosition);
    // Serial.print(" millis:");
    // Serial.print(millis());
    // Serial.print(" > ");
    // Serial.println(newDripDelayEnd);
    
    if (!dripCount || millis() > newDripDelayEnd) {
        newDripDelayEnd = 0;
        dripStarts[d] = millis();
        dripColors[d] = randomGreen();
        dripWidth[d] = random(REST_DRIP_WIDTH_MIN, REST_DRIP_WIDTH_MAX);
        dripEaten[d] = false;
        dripEase[d].setDuration(float(REST_DRIP_TRIP_MS));
        dripEase[d].setTotalChangeInPosition(float(ledsPerStrip*2));
        dripCount++;
    }
}

bool hasNewRandomBreath() {
#ifndef RANDOMBREATHS
    return false;
#endif
    
    if (activeBreath != -1) return false;
    
    if (millis() > lastNewBreathMs) {
        // Serial.print(" ---> millis() > lastNewBreathMs: ");
        // Serial.print(millis());
        // Serial.print(" > ");
        // Serial.print(lastNewBreathMs);
        // Serial.print(" - ");
        // Serial.println(endActiveBreathMs);
        endActiveBreathMs = millis() + random(500, 1000);
        lastNewBreathMs = endActiveBreathMs + random(800, 1550);
        // Serial.print(" -> (Now) ");
        // Serial.print(lastNewBreathMs);
        // Serial.print(" - ");
        // Serial.println(endActiveBreathMs);
        return true;
    }
    
    // Serial.print(" ---> hasNewBreath is not stale nor running: ");
    // Serial.print(millis());
    // Serial.print(" < ");
    // Serial.print(lastNewBreathMs);
    // Serial.print(" - ");
    // Serial.println(endActiveBreathMs);
    
    return false;
}

bool hasNewBreath() {
    if (activeBreath != -1) return false;
    
    if (detectedBreath) {
        Serial.println(" ---> hasNewBreath has detected a breath");
        return true;
    }
    
    Serial.println(" ---> No detected breath and no inactive breath");
    
    return false;
}

bool hasActiveRandomBreath() {
#ifndef RANDOMBREATHS
    return false;
#endif
    if (activeBreath == -1) return false;
    
    if (millis() < endActiveBreathMs) {
        return true;
    }
    
    activeBreath = -1;
    
    return false;
}

bool hasActiveBreath() {
    return detectedBreath;
}
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

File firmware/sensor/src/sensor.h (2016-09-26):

#include <Ultrasonic.h>
#include <Servo.h>
#include <avr/power.h>
#include <Adafruit_NeoPixel.h>
#include <SPI.h>
#include <SI114.h>

// #define USE_IR_PROX
// #define FAKE_PROX


#define NEO_PIXEL_PIN 8
#define ULTRASONIC_ANALOG_PIN 17
#define RAW_VOLT_ANALOG_WIND_SENSOR_PIN 1
#define TEMPERATURE_ANALOG_WIND_SENSOR_PIN 2
#define PIR_PIN 20
#define SERVO_PIN 3
#define SI114_PORT 0
#define ULTRASONIC_2_TRIG_PIN 5
#define ULTRASONIC_2_ECHO_PIN 4

#define PIR_REMOTE_PIN 1
#define BREATH_REMOTE_PIN 0

Adafruit_NeoPixel leds = Adafruit_NeoPixel(2, NEO_PIXEL_PIN, NEO_GRB + NEO_KHZ800);

// Remote

long lastRemotePIRRead = 0;
const long remotePIRReadInteval = 100;

// LEDs

int ledCloseColorR = 0, ledCloseColorG = 0, ledCloseColorB = 0;
int ledOpenColorR = 255, ledOpenColorG = 85, ledOpenColorB = 0;
int ledProxColorR = 255, ledProxColorG = 85, ledProxColorB = 85;

int ledStartColorR = 0, ledStartColorG = 0, ledStartColorB = 0;
int ledEndColorR = 255, ledEndColorG = 255, ledEndColorB = 0;

const long fadeTime = 10000;
long fadeStartTime = -2*fadeTime;

long ledUpdateInterval = 100;
long lastLedUpdateTime = 0;

// Servo

Servo servo; 

const int servoClosePos = 35; // recommended servo angle to close the flower. (previous values used: 40)
const int servoOpenPos = 110; // recommended servo angle to open the flower (previous values used: 130)

const long flowerOpenTime = 5000;
long flowerOpenStartTime = -2*flowerOpenTime;
bool isOpenOrClosing = false;

int servoTargetPosition = servoOpenPos;
int servoStartPosition = servoOpenPos;
int servoPosition = servoOpenPos;

// Wind

const long windSampleInterval = 20;

long lastWindSampleTime = 0;
float lowWindAvgFactor = 0.6;
float lowWindAvg = 700;
float highWindAvgFactor = 0.98;
float highWindAvg = 700;
int bpassWind = 0;
int lastBpassWind = 0;

#define WIND_HIST_LEN 50
int windHistoryIndex = 0;
int windHistory[WIND_HIST_LEN];

typedef enum {
	BREATH,
	REST
} BreathState;
BreathState breathState = REST;

int windState = 0;

// UART to mainboard

// #define HWSERIAL Serial1

// PIR

const long pirSampleInterval = 20;
long lastPIRSampleTime = 0;

#define PIR_HIST_LEN 10
int pirHistoryIndex = 0;
int pirHistory[PIR_HIST_LEN];

typedef enum {
	PIR_ON,
	PIR_OFF
} PirState;

PirState pirState = PIR_OFF;

// New Ultrasonic with two eyes

Ultrasonic ultrasonic(ULTRASONIC_2_TRIG_PIN, ULTRASONIC_2_ECHO_PIN, 6000); // (Trig PIN, Echo PIN)

// Ultrasonic

const long ultraThres = 50;
const long ultraSampleInterval = 100;
long lastUltraSampleTime = 0;
bool isProximate = false;

#define ULTRA_HIST_LEN 10
int ultraHistoryIndex = 0;
int ultraHistory[ULTRA_HIST_LEN];

// IR prox

#ifdef USE_IR_PROX
	PortI2C pulseI2C(SI114_PORT);
	PulsePlug pulse(pulseI2C);
#endif

// App flow

typedef enum {
	STATE_NEUTRAL,
	STATE_OPEN,
	STATE_PROX
} SystemState;

SystemState overallState = STATE_NEUTRAL;

SystemState remoteState = STATE_NEUTRAL;

const long openTimeout = 5*1000;
long openTimeoutLastEvent = 0;

void closeFlower();
void openFlower();
void breathOff();
void breathOn();

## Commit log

2016-05-31 Stubbing in Teensy 3.2 makefile and code.
2016-06-01 Stubbing in board directories.
2016-06-01 Whoops, wasn't correctly adjusting offset, created an ever expanding loop. Much better.
    [grove.cpp, grove.h]
2016-06-07 Initial Commit of 2016 Main Board
    Has Teensy connector, input power path, level shifter, LED string connectors, 3V3 regulator.
    TODO: Status LEDs, pick a toggle switch, interface to sensor board, connector for HV LEDs
    [teensyShield_progLED.kicad_pcb, teensyShield_progLED.sch]
2016-06-09 Add the sch and libs for the dispatcher so far
    [grove-dispatcher.sch]
2016-06-09 Drop components on the PCB and add fuses
    [grove-dispatcher.kicad_pcb, grove-dispatcher.sch]
2016-06-09 Some test placement on PCB
    [grove-dispatcher.kicad_pcb]
2016-06-09 Some tweaks to the gitignore and pcb file
    [grove-dispatcher.kicad_pcb]
2016-06-10 First pass at routing this simple board
    Conn for LED are spaced far enough apart to allow
    for MTA connectors which are 0.3 inch or more thick
    [grove-dispatcher.kicad_pcb, grove-dispatcher.sch]
2016-06-10 Add some mounting holes
    [grove-dispatcher.kicad_pcb]
2016-06-10 Add a silk screen with name and revision
    [grove-dispatcher.kicad_pcb]
2016-06-13 Sensor footprint.
2016-06-18 Update the lib and sch with new parts
    * DAC now included
    * Added a 2.5V regulator (can be swapped for adj reg)
    to drive VDD so the output range of the DAC is 2.5V
    * Replaced inbound connector with 12 pin
    [grove-dispatcher.sch]
2016-06-18 Update annotations, footprints and net
    [grove-dispatcher.sch]
2016-06-19 Working on PCB some more
    [grove-dispatcher.kicad_pcb]
2016-06-19 Did all the routing
    [grove-dispatcher.kicad_pcb]
2016-06-19 Add edge cuts and zones
    [grove-dispatcher.kicad_pcb]
2016-06-19 Add test points to sch
    [grove-dispatcher.sch]
2016-06-19 Add some test points
    [grove-dispatcher.kicad_pcb]
2016-06-19 Added mouting holes
    [grove-dispatcher.kicad_pcb]
2016-06-19 Something changed and I didn't commit it?
    [grove-dispatcher.sch]
2016-06-20 Updated sch with some resistors for the signal pins
    [grove-dispatcher.sch]
2016-06-20 Add layout for resistors + more test points
    [grove-dispatcher.kicad_pcb, grove-dispatcher.sch]
2016-06-20 Update the pico buck footprint to fix pin placement error
    [grove-dispatcher.kicad_pcb]
2016-06-21 Final PCB file for Rev1
    [teensyShield_progLED.sch, teensyShield_progLED_FINAL_REV1.kicad_pcb]
2016-06-21 Update pin direction on some footprints
2016-06-21 Re add mounting holes
    [grove-dispatcher.kicad_pcb]
2016-06-21 Fill zones, merge segements and run DRC
    [grove-dispatcher.kicad_pcb]
2016-06-21 Fix changed connector ordering
    [grove-dispatcher.kicad_pcb, grove-dispatcher.sch]
2016-06-21 Update silk screen
    [grove-dispatcher.kicad_pcb]
2016-06-23 Draft sensor schematic
    [grove-sensor.kicad_pcb, grove-sensor.sch]
2016-06-23 Small correction to the pico buck mounting holes
    [grove-dispatcher.kicad_pcb, grove-dispatcher.sch]
2016-06-23 Rename some nets for debug/documentation
    [grove-dispatcher.kicad_pcb]
2016-06-23 Drew some footprints and PCB outline
    [_saved_grove-sensor.sch, grove-sensor.kicad_pcb]
2016-06-24 bunch of sensor stuff
    [grove-sensor.kicad_pcb, grove-sensor.sch]
2016-06-24 Update skilscreens
    [grove-dispatcher.kicad_pcb]
2016-06-24 Fix some hole sizes
    [grove-dispatcher.kicad_pcb]
2016-06-24 Adjust gerber settings and export
    [grove-dispatcher-B.Cu.gbr, grove-dispatcher-B.Mask.gbr, grove-dispatcher-B.SilkS.gbr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]
2016-06-24 Small gerber config changes
    [grove-dispatcher.kicad_pcb]
2016-06-29 Some fixes and placement changes
    [grove-sensor.kicad_pcb, grove-sensor.sch]
2016-06-30 Draft sensor route on 4 layers
    [grove-sensor.kicad_pcb, grove-sensor.sch]
2016-07-02 Working on some code to test the dispatcher board
    * Add SPI library
    * Setup SPI according to the BH2221FV datasheet
    * Add some bit operation helpers
    * Put color sweep code in main loop
    * temporarily comment out the main neo pixel loop code
    This code is still untested for now
2016-07-07 Revert some test code and add some comments for the dispatcher method
    [grove.cpp]
2016-07-07 Fixes and updates to sensor board
    [grove-sensor-B.Paste.gbr, grove-sensor-Bottom.gbr, grove-sensor-Edge.Cuts.gbr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]
2016-07-08 Fixing and adding colors, reversing drip direction, adding randomized drip lengths.
    [grove.cpp, grove.h]
2016-07-08 Adding LED strips back in.
2016-07-11 Added sensor mounting holes
    [_saved_grove-sensor.sch, grove-sensor.kicad_pcb]
2016-07-14 Temporarily switching pins to match the working DMA pins on the main board.
2016-07-29 Changes for rev 2 of sensor board
    [grove-sensor.kicad_pcb, grove-sensor.sch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]
2016-08-02 Stubbing in breaths. Fixing blinking bug on head pixel for rest drips.
    [grove.cpp, grove.h]
2016-08-04 Fixing bug around oddities when a new drip gets made but immediately eaten, resulting in flashing on the leaves.
    [grove.cpp, grove.h]
2016-08-05 Removed old gerbers, added v2
    [_saved_grove-sensor.sch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]
2016-08-08 changes req'd for rev b
    Changes:
    - remapped teensy pins to the ones used by the teensy neopixel library
    - added jumper options to connect LED string 4 to all four strings, and disconnect those from the circuit
    - added 5th LED string connector for the sensor stem thing
    - reserved necessary pins
    - removed overcurrent detect circuit because I didn't have a chance to test it, replaced with a PTC footprint which should be lesser risk
    - moved teensy main power to the input side of the load switch
    - added place to measure full load current
    - moved power supply mtg holes based on measurement of physical unit.
    - enlarged elec cap pads for easier hand soldering
    [teensyShield_progLED.kicad_pcb, teensyShield_progLED.sch]
2016-08-08 Moving main%20board to main\ board.
    [teensyShield_progLED.kicad_pcb, teensyShield_progLED.sch]
2016-08-10 Added test firmware for sensor
2016-08-10 LEDs to show breathing and proximity.
2016-08-15 Added ultrasound to sensor and fixed plane short
    [grove-sensor.sch]
2016-08-25 Anticipating the breath by 300ms to sync high currents with top of led strip.
2016-08-25 Fixing drip tail when eaten by breath.
    [grove.cpp]
2016-08-25 First pass at sensor firmware
2016-08-25 Working comms with all the sensor
2016-08-25 Playing around with some super basic wind filtering
2016-08-25 Test with the servo working
2016-08-26 Servo code with smooth movement
2016-08-26 Run the breath detection on a millis sampling interval (no delay)
2016-08-26 HWSerial comm with the main board
2016-08-26 Breathing now comes form the sensor. Needs tweaking and some PIR sensing.
2016-08-26 Added state machine flow
2016-08-26 Stubbing in logic to handle proximity state machine from sensor.
2016-08-26 Fade LEDs in/out
2016-08-26 Hacking with the IR sensor
2016-08-26 Fix led fadeout
2016-08-26 Fixing stuck pixel at very bottom.
    [grove.cpp, grove.h]
2016-08-27 Thresholds and prints
2016-08-27 Add the ultrasonic lib
2016-08-27 Various changes:
    * Ultrasonic doesn't reset PIR timeout
    * Probably fix led black issue
    * Open flower at start and then close slowly
    [_saved_grove-sensor.sch, grove-sensor.sch]
2016-08-27 Fix the leds being off
    [sensor.cpp]
2016-08-27 Update breath sensor to use a diff window
2016-08-27 Switch to remote PIR
2016-08-27 Adding PIR sensors to main board, transmitting to sensor board.
2016-08-29 Fix PIR and change serial prints
    [grove.cpp, sensor.cpp]
2016-08-29 Switch to digital comm on sensor board
2016-08-29 Debug inverted pin rx/tx issue
    [grove.cpp, sensor.cpp, sensor.h]
2016-08-29 Tweaking on playa, fixing some bugs with breaths and sensing
    [grove.cpp, sensor.cpp, sensor.h]
2016-08-29 Turn off breathing when proximity sensor goes low.
2016-08-30 Colors of sensor and trunk.
2016-08-30 Disable prox for now on flower
2018-01-14 Updating teensy.
